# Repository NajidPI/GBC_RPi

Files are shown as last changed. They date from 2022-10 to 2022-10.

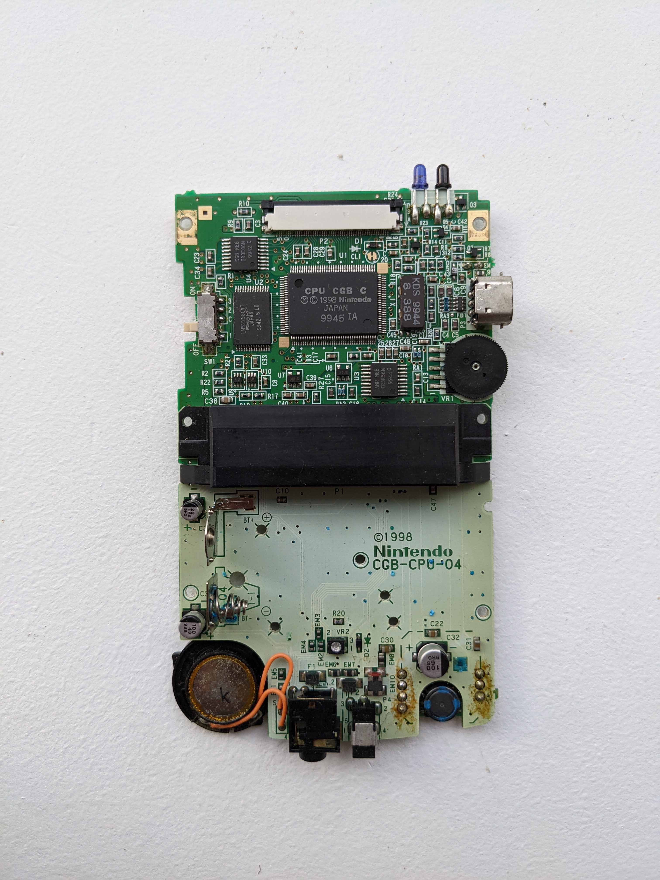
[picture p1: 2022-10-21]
motherboard_back.jpg

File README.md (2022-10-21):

# GBC_RPi
This repository includes all files required to build a functioning Gameboy Colour by retrofitting the shell with a Raspberry Pi

folders:

install - To start designing from scratch. These are the necessary versions for running KiCAD with Autorouter

GBC_motherboard - Files for a PCB design made in KiCAD and generated gerber files for printing

gbc -  holds all games loaded on the raspberry pi

Game_Boy_Zero - File to program Teensy board for gaming controls

Future works:
Merge all breakout boards onto motherboard

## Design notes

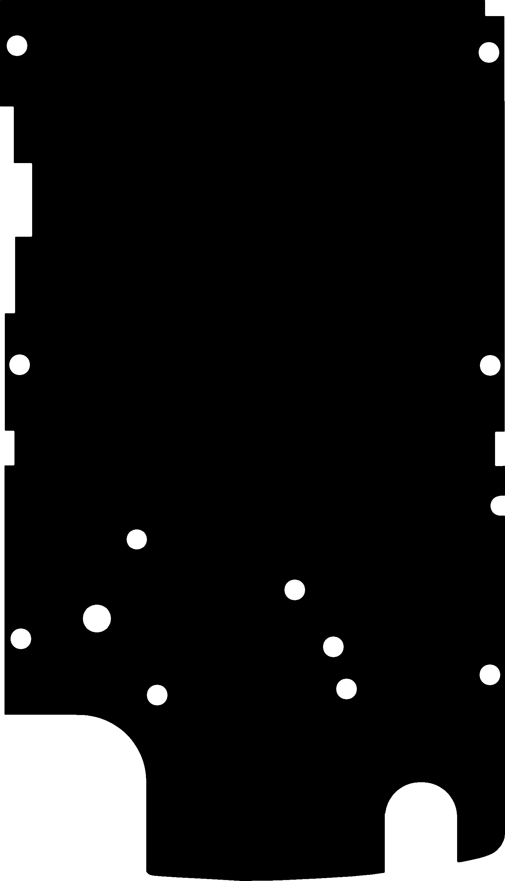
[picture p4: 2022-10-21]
outline_dark_fill.jpg

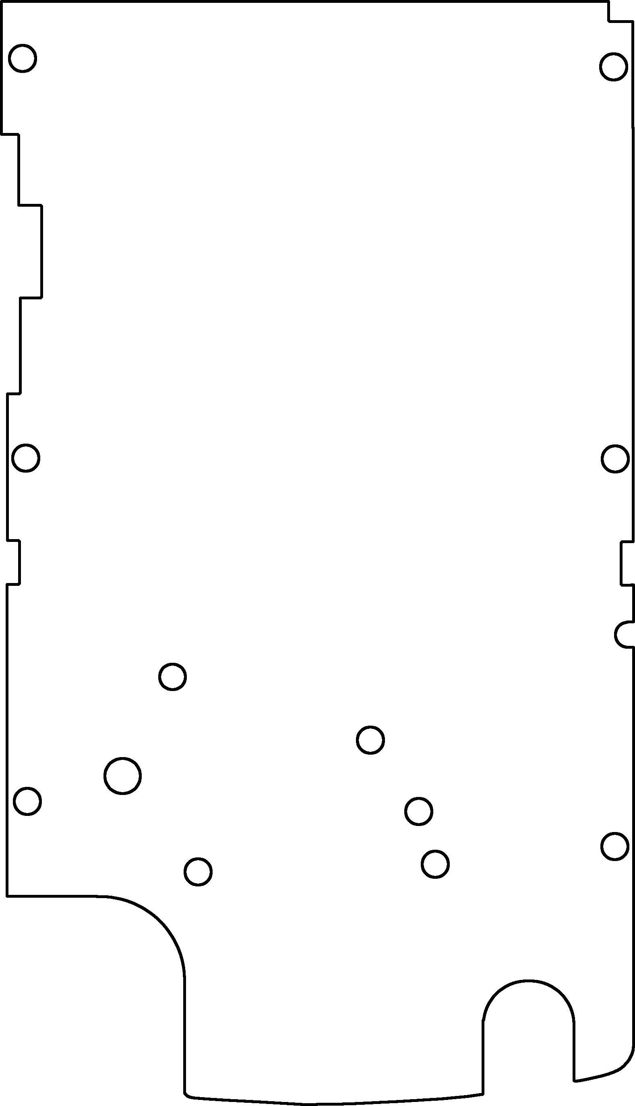
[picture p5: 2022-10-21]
outline_white_background.jpg

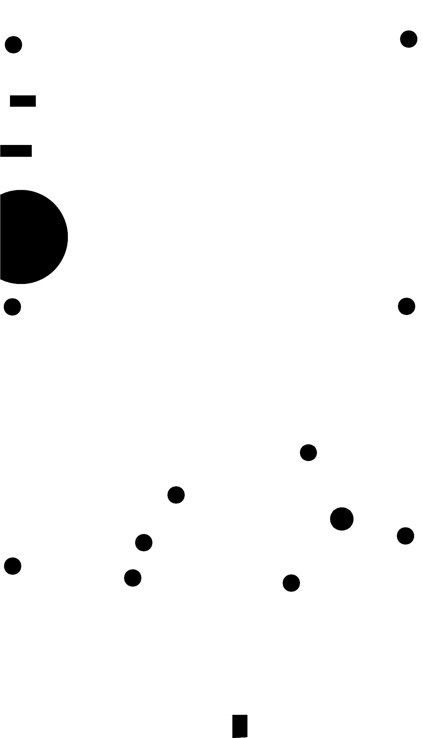
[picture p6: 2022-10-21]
peripherals.jpg

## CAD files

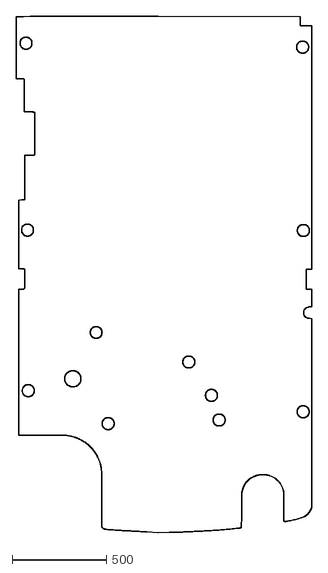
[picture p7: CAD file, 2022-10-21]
GBC_motherboard/outline_dark_fill.dxf
1570.3 x 2738.9

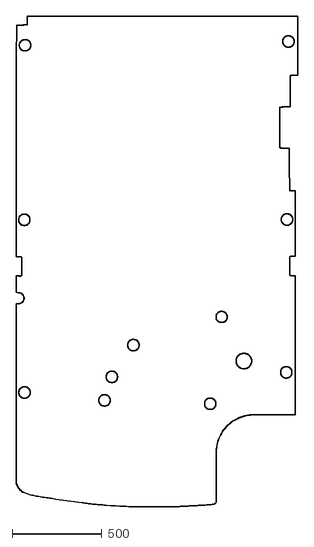
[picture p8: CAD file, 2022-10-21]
GBC_motherboard/outline_2.dxf
1570.0 x 2735.8

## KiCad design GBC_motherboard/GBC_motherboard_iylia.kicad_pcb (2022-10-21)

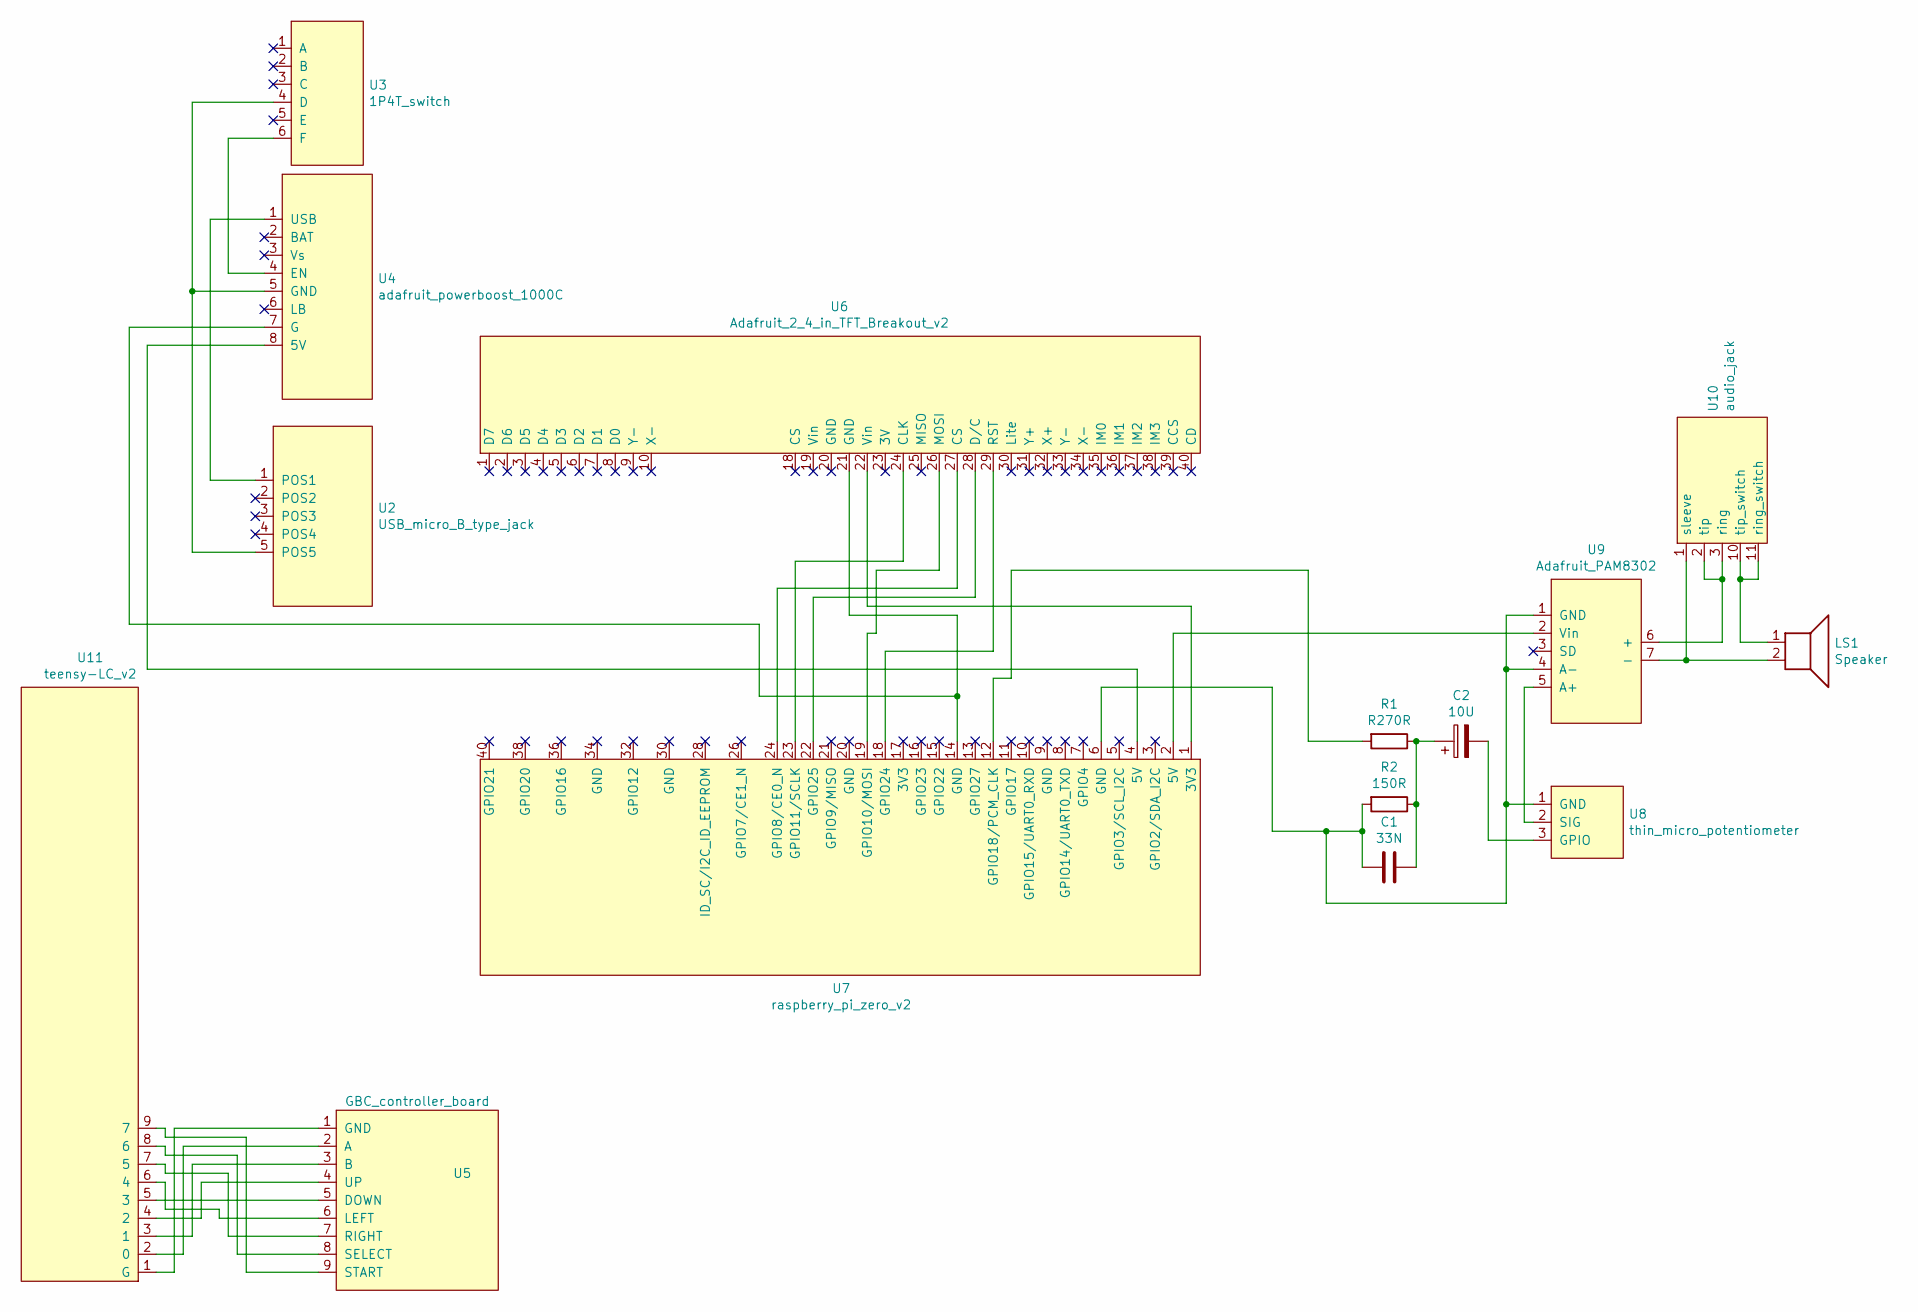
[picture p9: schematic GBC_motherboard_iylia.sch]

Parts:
C1: 33N; C_1206_3216Metric_Pad1.33x1.80mm_HandSolder
C2: 10U; C_1206_3216Metric_Pad1.33x1.80mm_HandSolder
LS1: Speaker; PinHeader_1x02_P2.54mm_Vertical
R1: R270R; R_1206_3216Metric_Pad1.30x1.75mm_HandSolder
R2: 150R; R_1206_3216Metric_Pad1.30x1.75mm_HandSolder
U2: USB_micro_B_type_jack
U3: 1P4T_switch
U4: adafruit_powerboost_1000C; adafruit_powerboost_1000c
U5: GBC_controller_board
U6: Adafruit_2_4_in_TFT_Breakout_v2
U7: raspberry_pi_zero_v2
U8: thin_micro_potentiometer
U9: Adafruit_PAM8302
U10: audio_jack
U11: teensy-LC_v2

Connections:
unnamed: C1.1, C2.1, R1.1, R2.1
unnamed: C1.2, R2.2, U7.6 (GND), U8.1 (GND), U9.1 (GND), U9.4 (A-)
unnamed: C2.2, U8.3 (GPIO)
unnamed: LS1.1, U10.10 (tip_switch), U10.11 (ring_switch)
unnamed: LS1.2, U9.7 (-), U10.1 (sleeve)
unnamed: R1.2, U7.12 (GPIO18/PCM_CLK)
unnamed: U2.1 (POS1), U4.1 (USB)
unnamed: U2.5 (POS5), U3.4 (D), U4.5 (GND)
unnamed: U3.6 (F), U4.4 (EN)
unnamed: U4.7 (G), U6.21 (GND), U7.14 (GND)
unnamed: U4.8 (5V), U7.4 (5V)
unnamed: U6.22 (Vin), U7.1 (3V3)
unnamed: U6.24 (CLK), U7.23 (GPIO11/SCLK)
unnamed: U6.26 (MOSI), U7.19 (GPIO10/MOSI)
unnamed: U6.27 (CS), U7.24 (GPIO8/CE0_N)
unnamed: U6.28 (D/C), U7.22 (GPIO25)
unnamed: U6.29 (RST), U7.18 (GPIO24)
unnamed: U7.2 (5V), U9.2 (Vin)
unnamed: U8.2 (SIG), U9.5 (A+)
unnamed: U9.6 (+), U10.2 (tip), U10.3 (ring)
unnamed: U5.1 (GND), U11.1 (G)
unnamed: U5.2 (A), U11.2 (0)
unnamed: U5.3 (B), U11.3 (1)
unnamed: U5.4 (UP), U11.4 (2)
unnamed: U5.5 (DOWN), U11.5 (3)
unnamed: U5.6 (LEFT), U11.6 (4)
unnamed: U5.7 (RIGHT), U11.7 (5)
unnamed: U5.8 (SELECT), U11.8 (6)
unnamed: U5.9 (START), U11.9 (7)

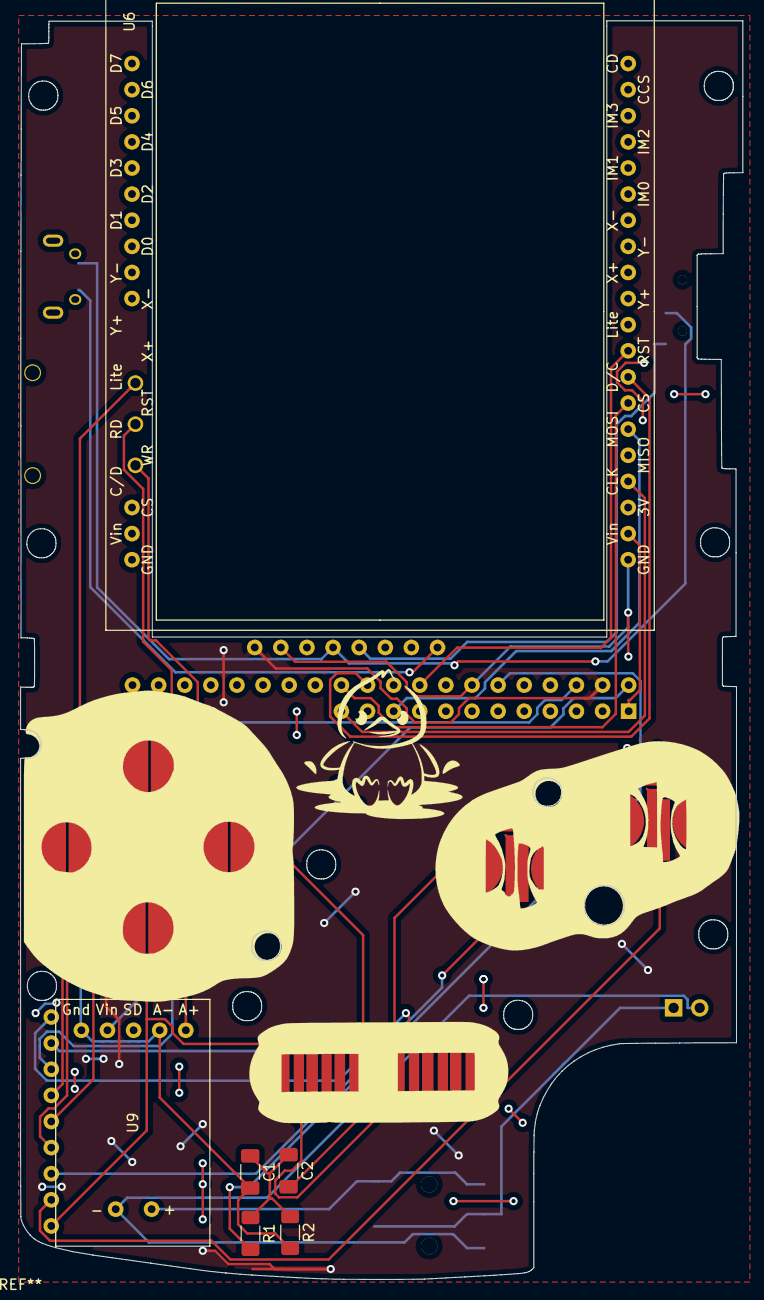
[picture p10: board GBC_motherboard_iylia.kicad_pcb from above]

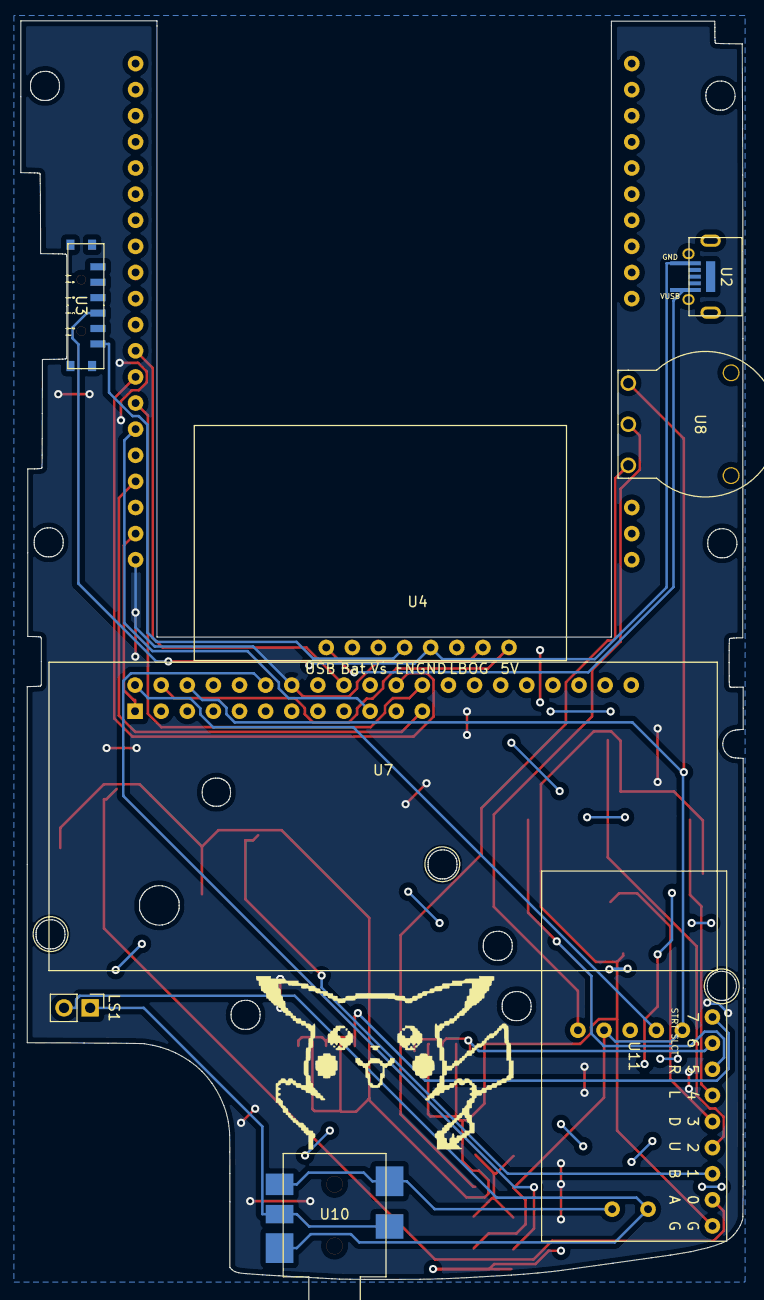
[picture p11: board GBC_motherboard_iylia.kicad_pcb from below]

Board: 2 copper layers, 70.3 x 122.4 mm, 17 parts (9 on the bottom side), 29 nets.

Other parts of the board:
G1: LOGO; cute-duck
G2: LOGO; pikachu

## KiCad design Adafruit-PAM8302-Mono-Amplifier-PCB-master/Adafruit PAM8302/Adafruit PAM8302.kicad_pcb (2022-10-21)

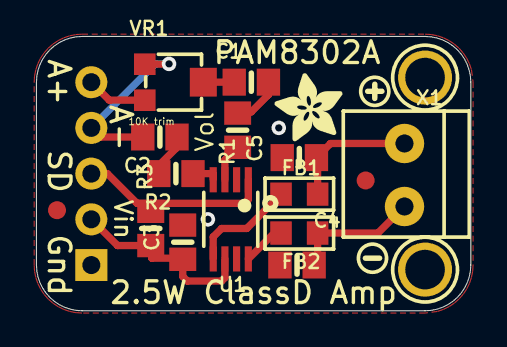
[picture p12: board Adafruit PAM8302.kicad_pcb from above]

Board: 2 copper layers, 24.1 x 15.2 mm, 22 parts (0 on the bottom side), 14 nets.

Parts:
C1, C2: 1uF; 0805-NO
C3: 10uF; 0805-NO
C4, C5: 220pF; 0805-NO
FB1, FB2: Ferrite; _0805
FID1, FID2: FIDUCIAL; FIDUCIAL_1MM
JP1: HEADER-1X570MIL; 1X05_ROUND_70
R1, R2: 100; 0805-NO
R3: 10K; 0805-NO
U1: PAM8302AASCR; MSOP8_0.65MM
U$3: SYMBOL_PLUS
U$4: SYMBOL_MINUS
U$5: ADAFRUIT_3.5MM
U$6: PCBFEAT-REV-040
U$10, U$11: MOUNTINGHOLE2.0; MOUNTINGHOLE_2.0_PLATED
VR1: 10K trim; TRIMPOT_BOURNS_3303W
X1: TERMBLOCK_1X2; TERMBLOCK_1X2-3.5MM

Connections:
/AIN+: JP1.5, VR1.3
/AIN-: C2.2, JP1.4, VR1.1
/SD: JP1.3, R3.2, U1.1
/VO+: C5.1, FB1.2, X1.1
/VO-: C4.1, FB2.2, X1.2
GND: C3.2, C4.2, C5.2, JP1.1, U1.7
unnamed: C1.1, R1.1
unnamed: C1.2, VR1.2
unnamed: C2.1, R2.1
unnamed: FB1.1, U1.5
unnamed: FB2.1, U1.8
unnamed: R1.2, U1.3
unnamed: R2.2, U1.4
VCC: C3.1, JP1.2, R3.1, U1.6

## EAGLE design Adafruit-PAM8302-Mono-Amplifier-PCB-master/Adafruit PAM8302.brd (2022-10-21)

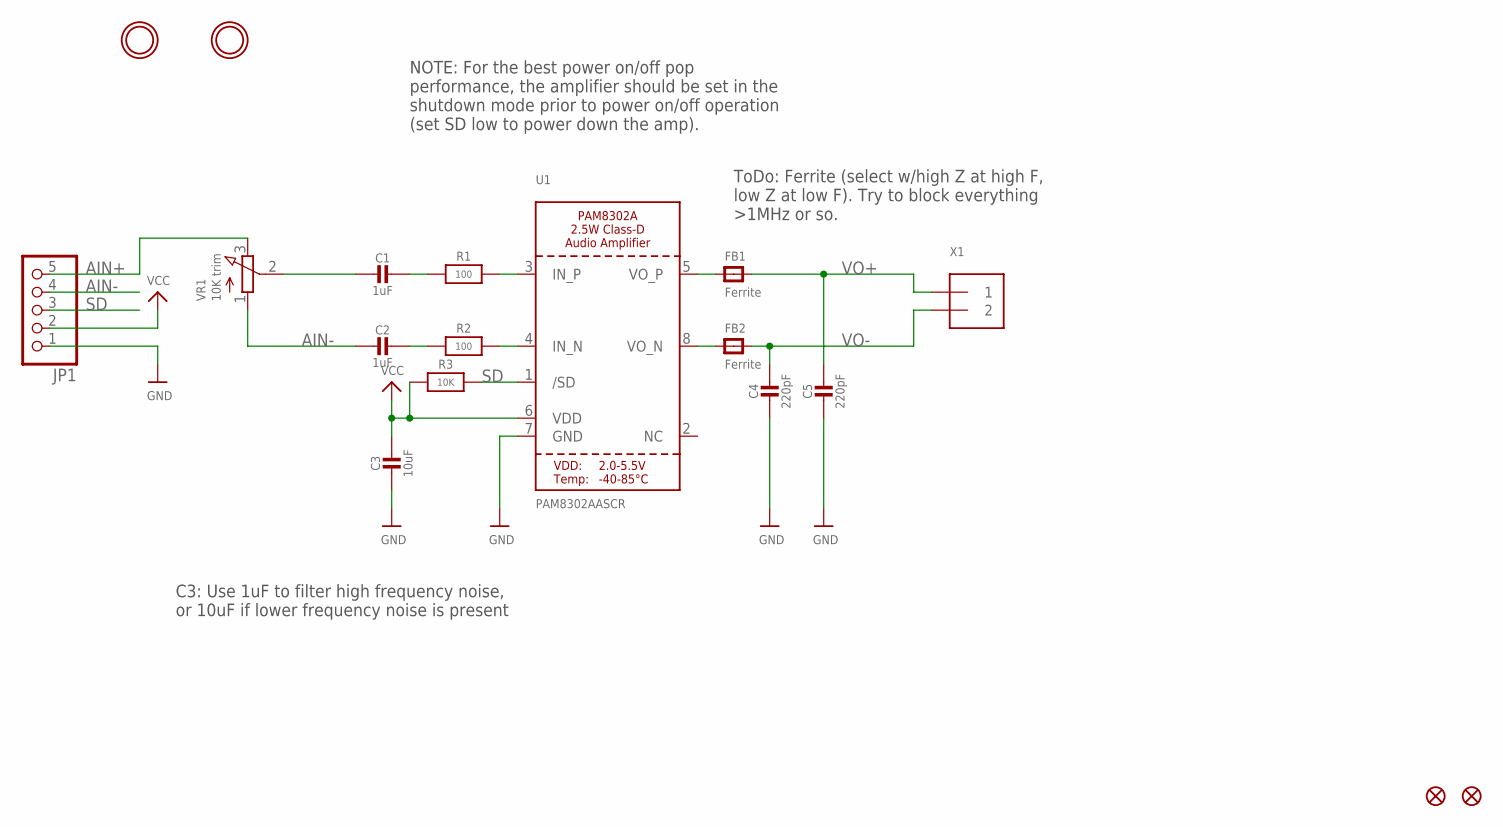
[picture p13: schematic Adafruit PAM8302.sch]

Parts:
C1, C2: 1uF; 0805-NO
C3: 10uF; 0805-NO
C4, C5: 220pF; 0805-NO
FB1, FB2: Ferrite; _0805
FID1, FID2: FIDUCIAL""; FIDUCIAL_1MM
JP1: HEADER-1X570MIL; 1X05_ROUND_70
R1, R2: 100; 0805-NO
R3: 10K; 0805-NO
U1: PAM8302AASCR; MSOP8_0.65MM
U$10, U$11: MOUNTINGHOLE2.0; MOUNTINGHOLE_2.0_PLATED
VR1: 10K trim; TRIMPOT_BOURNS_3303W
X1: TERMBLOCK_1X2; TERMBLOCK_1X2-3.5MM

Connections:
AIN+: JP1.5, VR1.3 (E)
AIN-: C2.2, JP1.4, VR1.1 (A)
GND: C3.2, C4.2, C5.2, JP1.1, U1.7 (GND)
unnamed: R2.2, U1.4 (IN_N)
unnamed: R1.2, U1.3 (IN_P)
unnamed: C1.1, R1.1
unnamed: C2.1, R2.1
unnamed: FB2.1, U1.8 (VO_N)
unnamed: FB1.1, U1.5 (VO_P)
unnamed: C1.2, VR1.2 (S)
SD: JP1.3, R3.2, U1.1 (/SD)
VCC: C3.1, JP1.2, R3.1, U1.6 (VDD)
VO+: C5.1, FB1.2, X1.1
VO-: C4.1, FB2.2, X1.2

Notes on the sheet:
ToDo: Ferrite (select w/high Z at high F, low Z at low F). Try to block everything >1MHz or so.
C3: Use 1uF to filter high frequency noise, or 10uF if lower frequency noise is present
NOTE: For the best power on/off pop performance, the amplifier should be set in the shutdown mode prior to power on/off operation (set SD low to power down the amp).

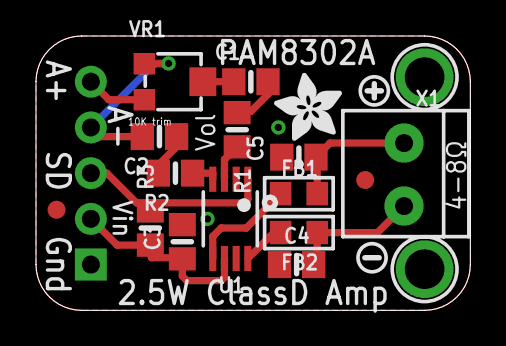
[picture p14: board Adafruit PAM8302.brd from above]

Board: 2 copper layers, 24.1 x 15.2 mm, 22 parts (1 on the bottom side), 14 nets.

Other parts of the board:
U$3: SYMBOL_PLUS
U$4: SYMBOL_MINUS
U$5: ADAFRUIT_3.5MM
U$6: PCBFEAT-REV-040

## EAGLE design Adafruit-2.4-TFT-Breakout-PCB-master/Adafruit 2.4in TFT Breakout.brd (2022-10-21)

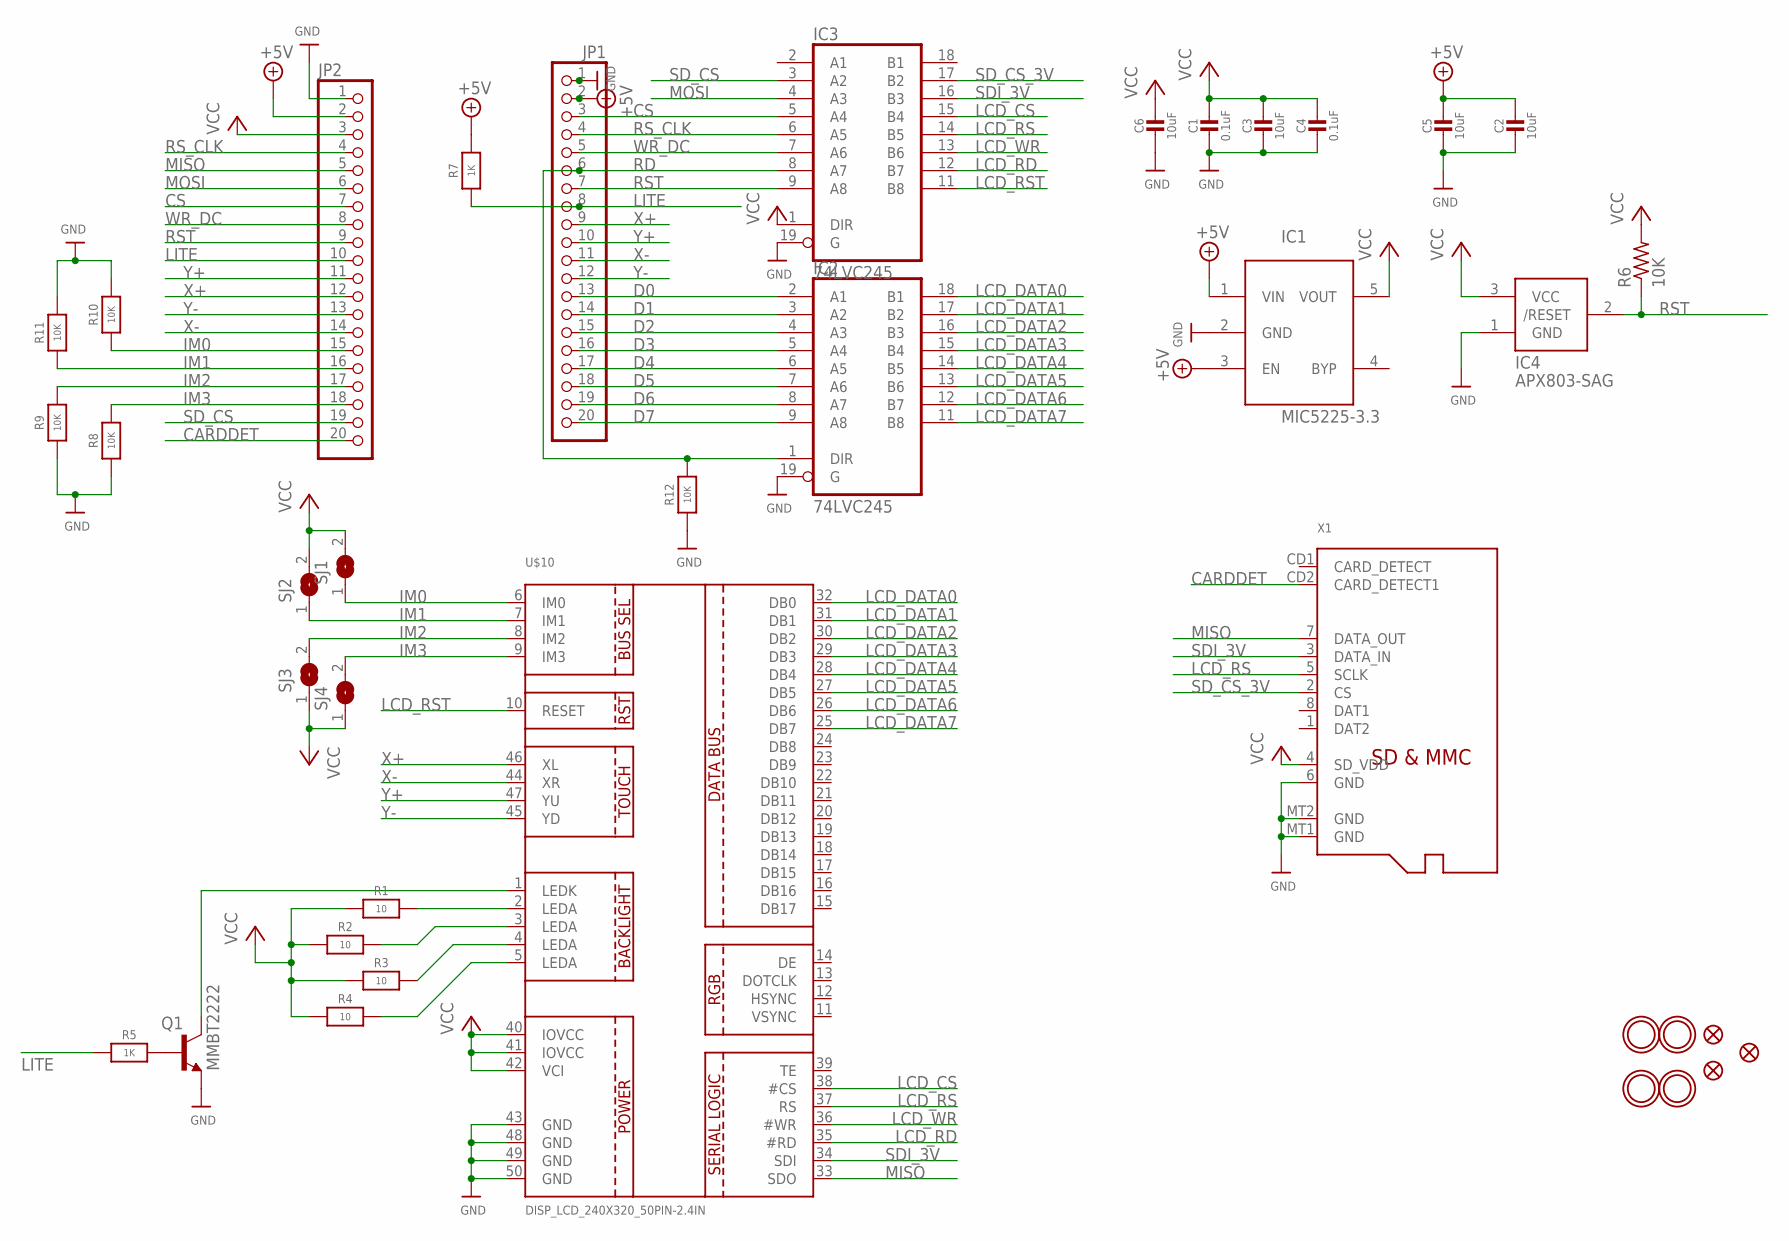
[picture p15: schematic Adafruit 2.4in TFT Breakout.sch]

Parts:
C1, C4: 0.1uF; 0805-NO
C2, C3, C5, C6: 10uF; 0805-NO
IC1: MIC5225-3.3; SOT23-5L
IC2, IC3: 74LVC245; SO20W
IC4: APX803-SAG; SOT23
JP1, JP2: HEADER-1X20ROUND; 1X20_ROUND
Q1: MMBT2222; SOT23-BEC
R1, R2, R3, R4: 10; 0805-NO
R5, R7: 1K; 0805-NO
R6: 10K; R0805
R8, R9, R10, R11, R12: 10K; 0805-NO
SJ1, SJ2, SJ3, SJ4: SOLDERJUMPER; SOLDERJUMPER_ARROW_NOPASTE
U$7, U$15, U$16, U$17: MOUNTINGHOLE2.5; MOUNTINGHOLE_2.5_PLATED
U$9, U$11, U$23: FIDUCIAL""; FIDUCIAL_1MM
U$10: DISP_LCD_240X320_50PIN-2.4IN; TFT_2.4IN_240X320_50PIN
X1: MICROSD

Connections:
+3V: C1.1, C3.1, C4.1, C6.1, IC1.5 (VOUT), IC2.20 (VCC), IC3.1 (DIR), IC3.20 (VCC), IC4.3 (VCC), JP2.3, R1.1, R2.1, R3.1, R4.1, R6.2, SJ1.2, SJ2.2, SJ3.1, SJ4.1, U$10.40 (IOVCC), U$10.41 (IOVCC), U$10.42 (VCI), X1.4 (SD_VDD)
CARDDET: JP2.20, X1.CD2 (CARD_DETECT1)
CS: IC3.5 (A4), JP1.3, JP2.7
D0: IC2.2 (A1), JP1.13
D1: IC2.3 (A2), JP1.14
D2: IC2.4 (A3), JP1.15
D3: IC2.5 (A4), JP1.16
D4: IC2.6 (A5), JP1.17
D5: IC2.7 (A6), JP1.18
D6: IC2.8 (A7), JP1.19
D7: IC2.9 (A8), JP1.20
GND: C1.2, C2.2, C3.2, C4.2, C5.2, C6.2, IC1.2 (GND), IC2.10 (GND), IC2.19 (G), IC3.10 (GND), IC3.19 (G), IC4.1 (GND), JP1.1, JP2.1, Q1.E, R8.1, R9.1, R10.2, R11.2, R12.1, U$10.43 (GND), U$10.48 (GND), U$10.49 (GND), U$10.50 (GND), X1.6 (GND), X1.MT1 (GND), X1.MT2 (GND)
IM0: JP2.15, R10.1, SJ1.1, U$10.6 (IM0)
IM1: JP2.16, R11.1, SJ2.1, U$10.7 (IM1)
IM2: JP2.17, R9.2, SJ3.2, U$10.8 (IM2)
IM3: JP2.18, R8.2, SJ4.2, U$10.9 (IM3)
LCD_CS: IC3.15 (B4), U$10.38 (#CS)
LCD_DATA0: IC2.18 (B1), U$10.32 (DB0)
LCD_DATA1: IC2.17 (B2), U$10.31 (DB1)
LCD_DATA2: IC2.16 (B3), U$10.30 (DB2)
LCD_DATA3: IC2.15 (B4), U$10.29 (DB3)
LCD_DATA4: IC2.14 (B5), U$10.28 (DB4)
LCD_DATA5: IC2.13 (B6), U$10.27 (DB5)
LCD_DATA6: IC2.12 (B7), U$10.26 (DB6)
LCD_DATA7: IC2.11 (B8), U$10.25 (DB7)
LCD_RD: IC3.12 (B7), U$10.35 (#RD)
LCD_RS: IC3.14 (B5), U$10.37 (RS), X1.5 (SCLK)
LCD_RST: IC3.11 (B8), U$10.10 (RESET)
LCD_WR: IC3.13 (B6), U$10.36 (#WR)
LITE: JP1.8, JP2.10, R5.1, R7.1
MISO: JP2.5, U$10.33 (SDO), X1.7 (DATA_OUT)
MOSI: IC3.4 (A3), JP2.6
unnamed: R4.2, U$10.5 (LEDA)
unnamed: R1.2, U$10.2 (LEDA)
unnamed: R2.2, U$10.3 (LEDA)
unnamed: R3.2, U$10.4 (LEDA)
unnamed: Q1.C, U$10.1 (LEDK)
unnamed: Q1.B, R5.2
RD: IC2.1 (DIR), IC3.8 (A7), JP1.6, R12.2
RST: IC3.9 (A8), IC4.2 (/RESET), JP1.7, JP2.9, R6.1
RS_CLK: IC3.6 (A5), JP1.4, JP2.4
SDI_3V: IC3.16 (B3), U$10.34 (SDI), X1.3 (DATA_IN)
SD_CS: IC3.3 (A2), JP2.19
SD_CS_3V: IC3.17 (B2), X1.2 (CS)
VIN: C2.1, C5.1, IC1.1 (VIN), IC1.3 (EN), JP1.2, JP2.2, R7.2
WR_DC: IC3.7 (A6), JP1.5, JP2.8
X+: JP1.9, JP2.12, U$10.46 (XL)
X-: JP1.11, JP2.14, U$10.44 (XR)
Y+: JP1.10, JP2.11, U$10.47 (YU)
Y-: JP1.12, JP2.13, U$10.45 (YD)

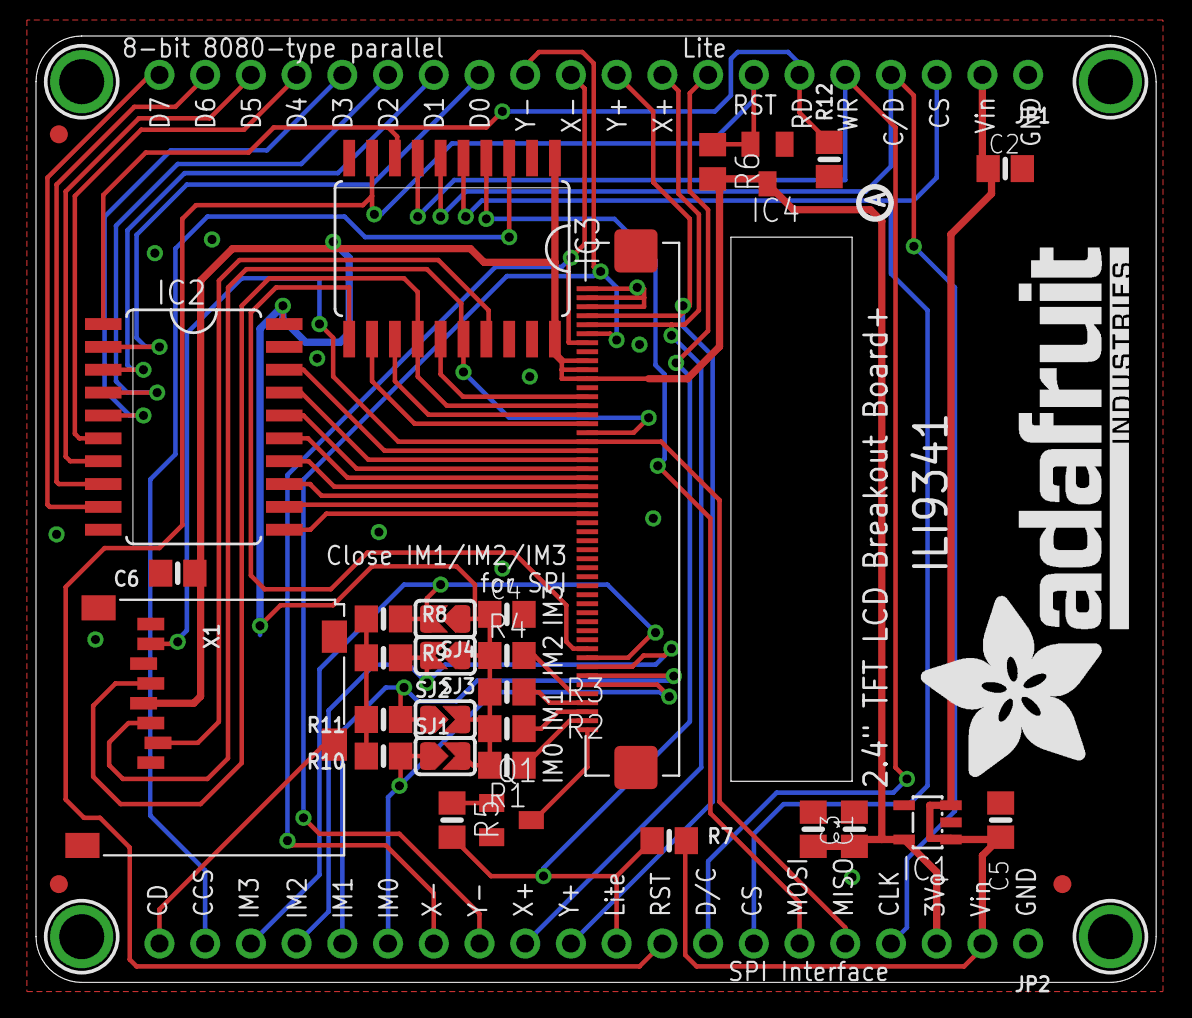
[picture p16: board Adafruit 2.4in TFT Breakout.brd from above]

Board: 2 copper layers, 62.2 x 52.6 mm, 40 parts (1 on the bottom side), 50 nets.

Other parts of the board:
U$19: ADAFRUIT_TEXT_30MM
U$26: PCBFEAT-REV-040

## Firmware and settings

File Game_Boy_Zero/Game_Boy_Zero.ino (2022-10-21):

#include <Bounce.h>

#define NUM_KEYS 12

struct Key {
  char keycode;
  Bounce* bounce;
};

Key keys[NUM_KEYS];

Key key(char keycode, int pin) {
  Key *ret = new Key;
  ret->keycode = keycode;
  ret->bounce = new Bounce(pin, 10);
  pinMode(pin, INPUT_PULLUP);
  return *ret;
}

void setupKeys() {
  keys[0] = key('w', 0);
  keys[1] = key('s', 1);
  keys[2] = key('a', 2);
  keys[3] = key('d', 3);
  keys[4] = key('p', 4);
  keys[5] = key('l', 5);
  keys[6] = key('o', 6);
  keys[7] = key('k', 7);
  keys[8] = key('x', 8);
  keys[9] = key('z', 9);
  keys[10] = key('q',10);
  keys[11] = key('e',11);
}

void setup() {
  setupKeys();
  Keyboard.begin();
  //  pinMode(0, INPUT_PULLUP);
}

void loop() {
  for (int i = 0; i < NUM_KEYS; i++) {
    keys[i].bounce->update();
    if (keys[i].bounce->fallingEdge()) {
      Keyboard.press(keys[i].keycode);
    } else if (keys[i].bounce->risingEdge()) {
      Keyboard.release(keys[i].keycode);
    }
  }
}

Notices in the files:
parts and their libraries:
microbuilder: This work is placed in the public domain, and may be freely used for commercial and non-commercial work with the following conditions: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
